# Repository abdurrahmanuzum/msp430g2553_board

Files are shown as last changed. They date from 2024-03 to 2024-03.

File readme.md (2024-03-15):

MSP430G2553 board with CH340 USB-UART bridge for programming.

**This board cannot do proper debugging.**

For programming script, see: https://github.com/gbhug5a/MSP430-BSL/tree/master

Can be run with the command: `<script_path>\BSLDEMO-2.01c.exe -cCOM<port#> -m1 -ijevpr <TI_HEX_filename.txt>`

Or can be embedded into the Code Composer Studio as a post-build step. Change the `<TI_HEX_filename.txt>` to `${BuildArtifactFileBaseName}.txt`. This will make the "Build" button to flash the program after building. (If building actually occurs, remember that the IDE will not build the identical project twice unless forced to. "nothing to build...")

CCS doesn't generate the output file by default, do: Project -> Properties -> Build -> MSP430 HEX Utility -> (1) Tick Enable 'MSP430 Hex Utility' -> Output Format Options -> (2) Select Output format: "TI-TXT hex --ti_txt"

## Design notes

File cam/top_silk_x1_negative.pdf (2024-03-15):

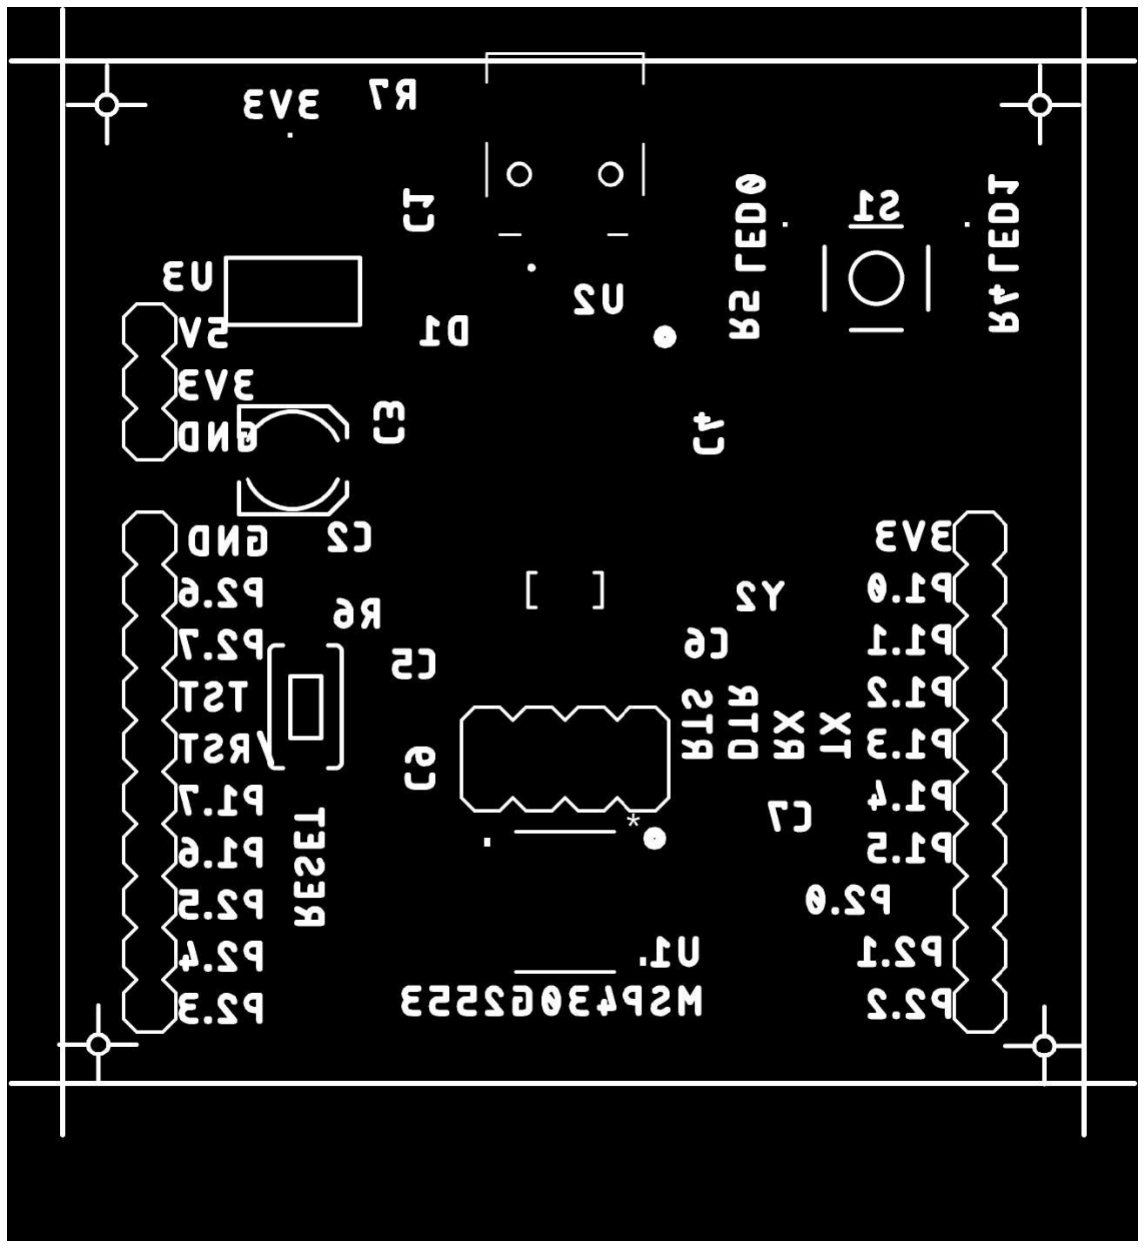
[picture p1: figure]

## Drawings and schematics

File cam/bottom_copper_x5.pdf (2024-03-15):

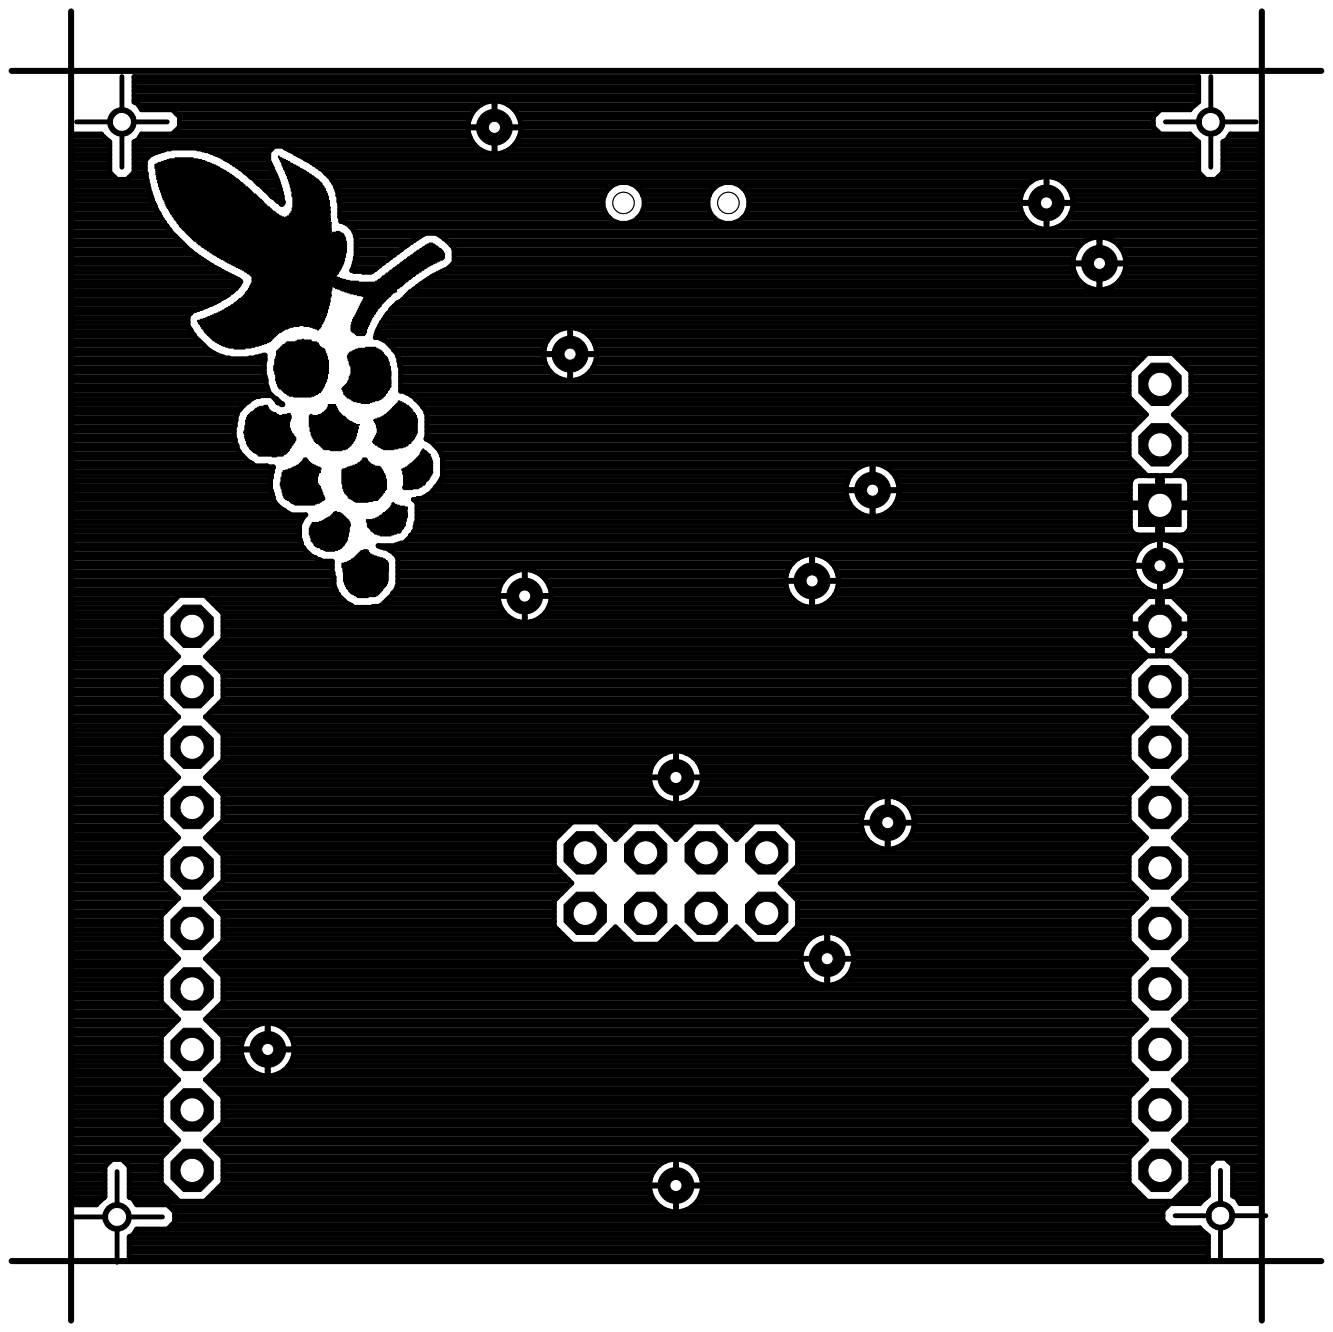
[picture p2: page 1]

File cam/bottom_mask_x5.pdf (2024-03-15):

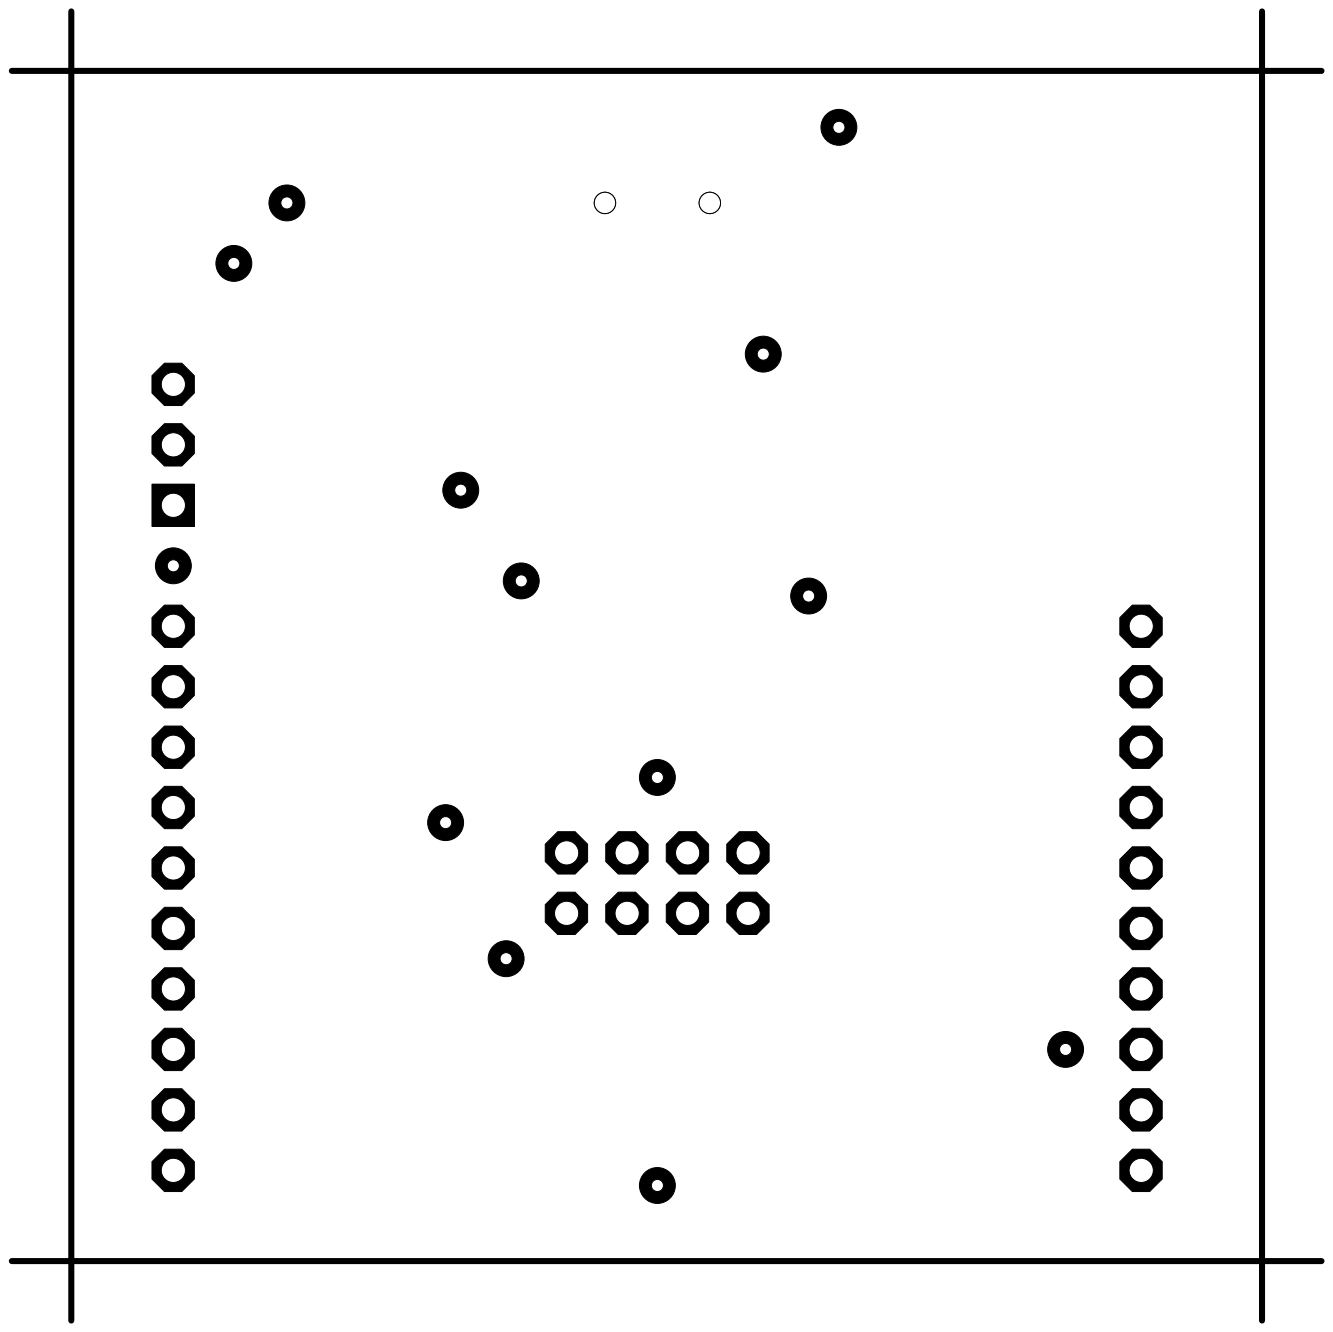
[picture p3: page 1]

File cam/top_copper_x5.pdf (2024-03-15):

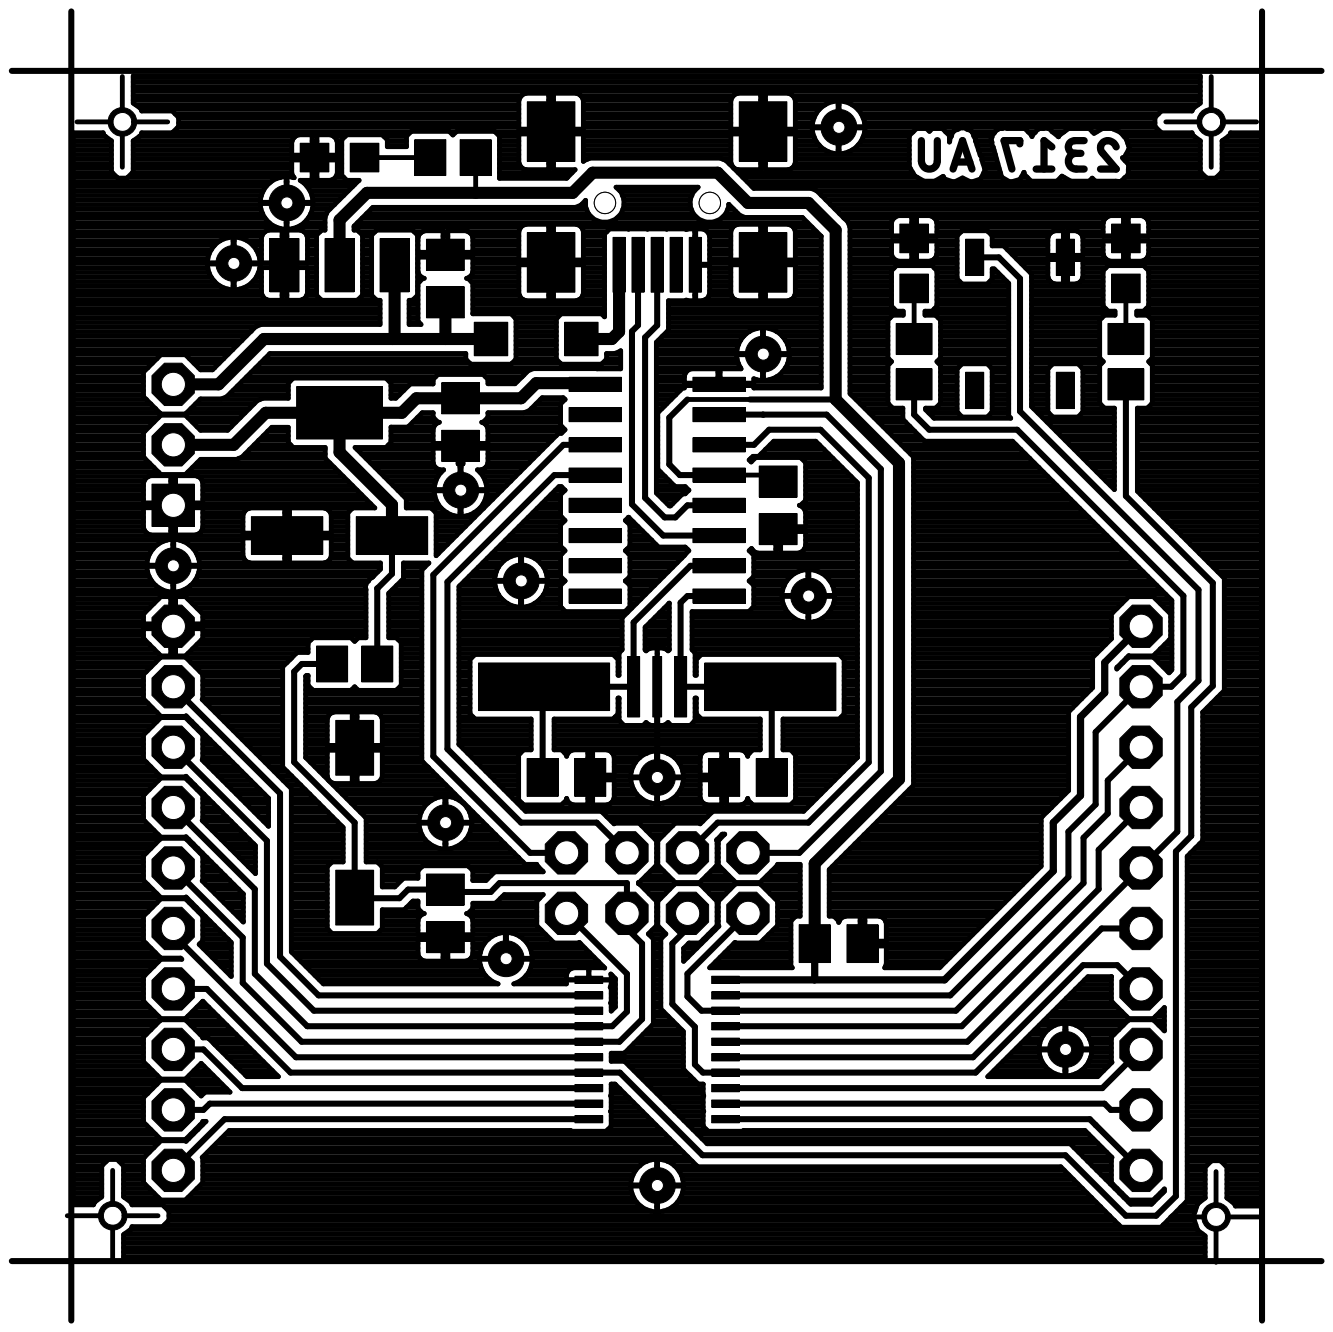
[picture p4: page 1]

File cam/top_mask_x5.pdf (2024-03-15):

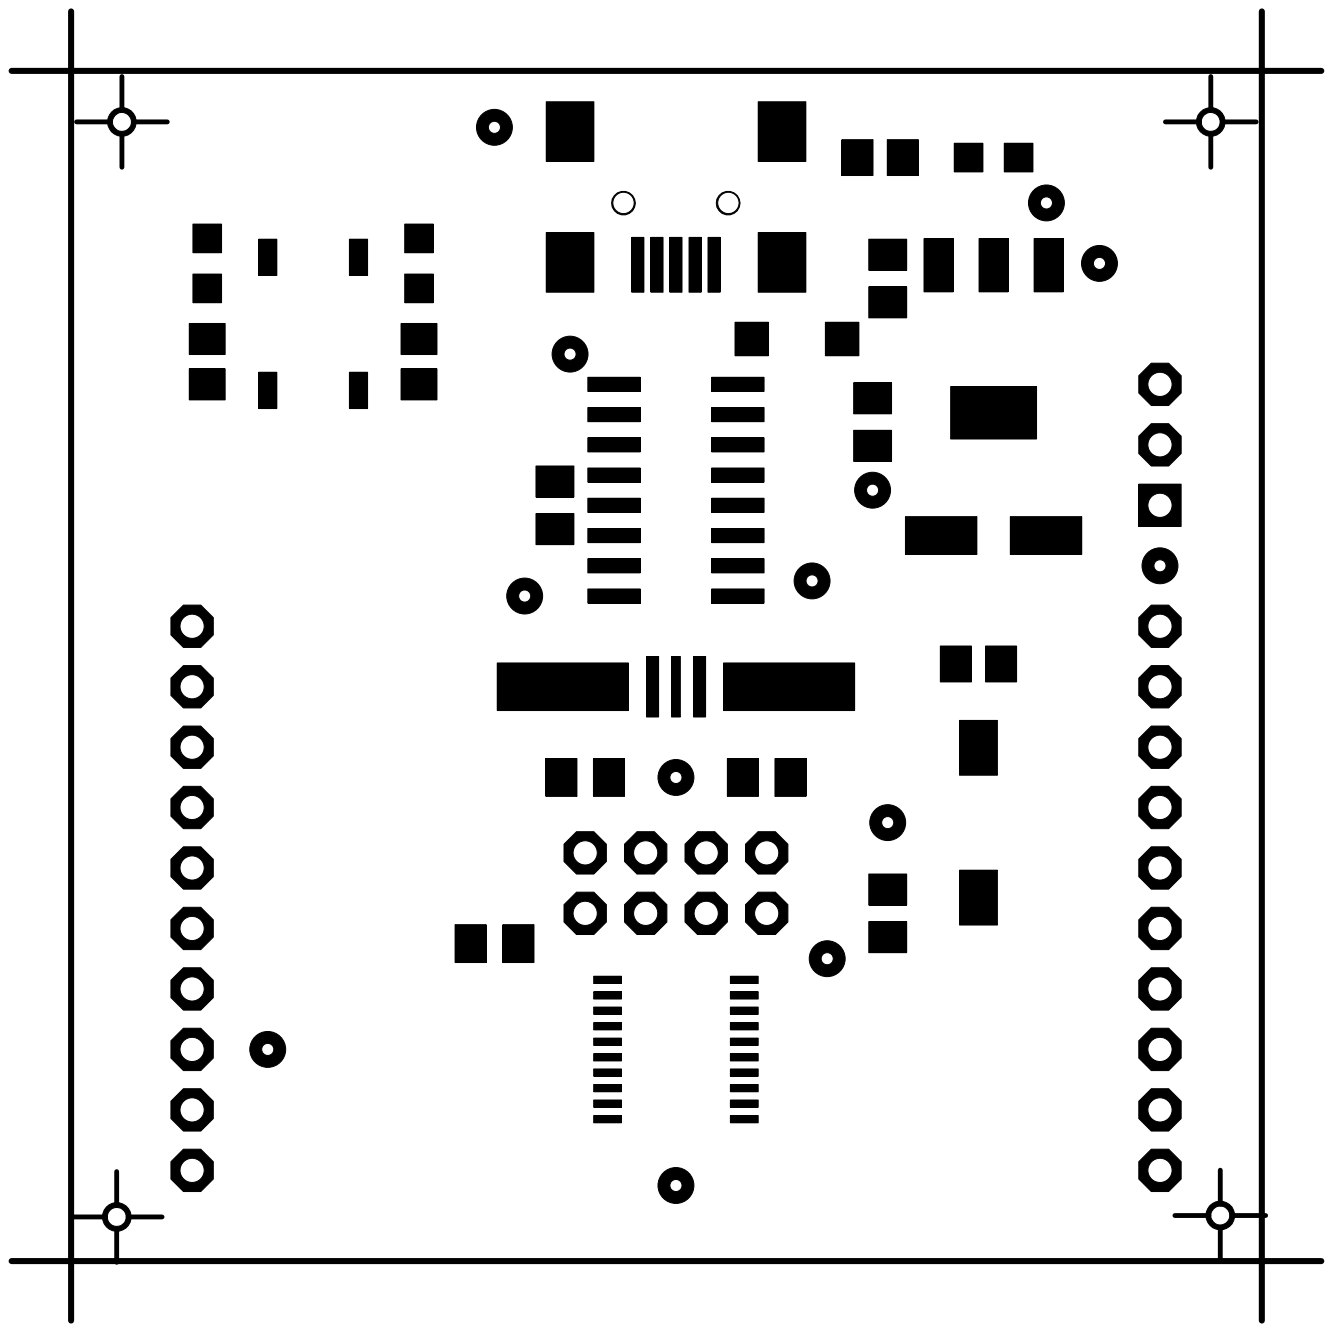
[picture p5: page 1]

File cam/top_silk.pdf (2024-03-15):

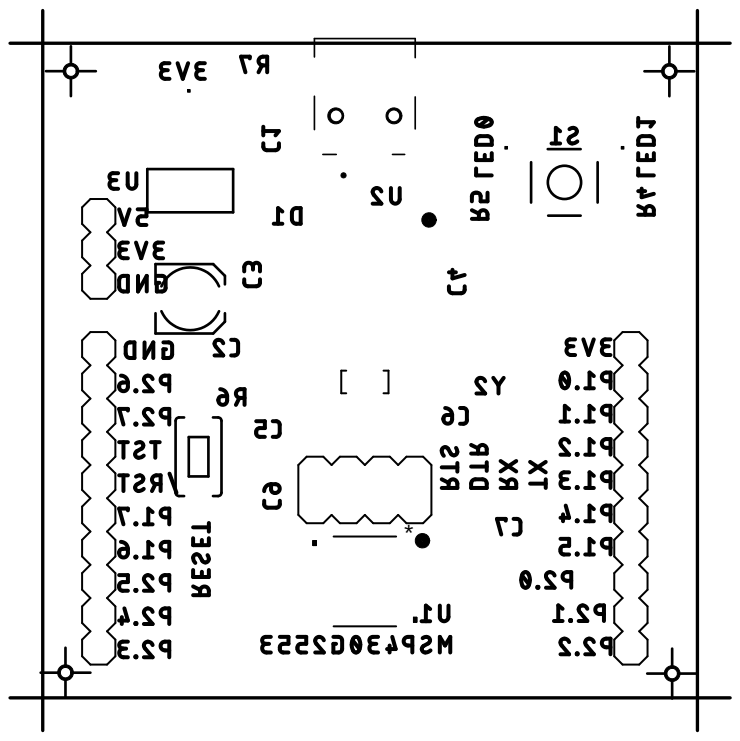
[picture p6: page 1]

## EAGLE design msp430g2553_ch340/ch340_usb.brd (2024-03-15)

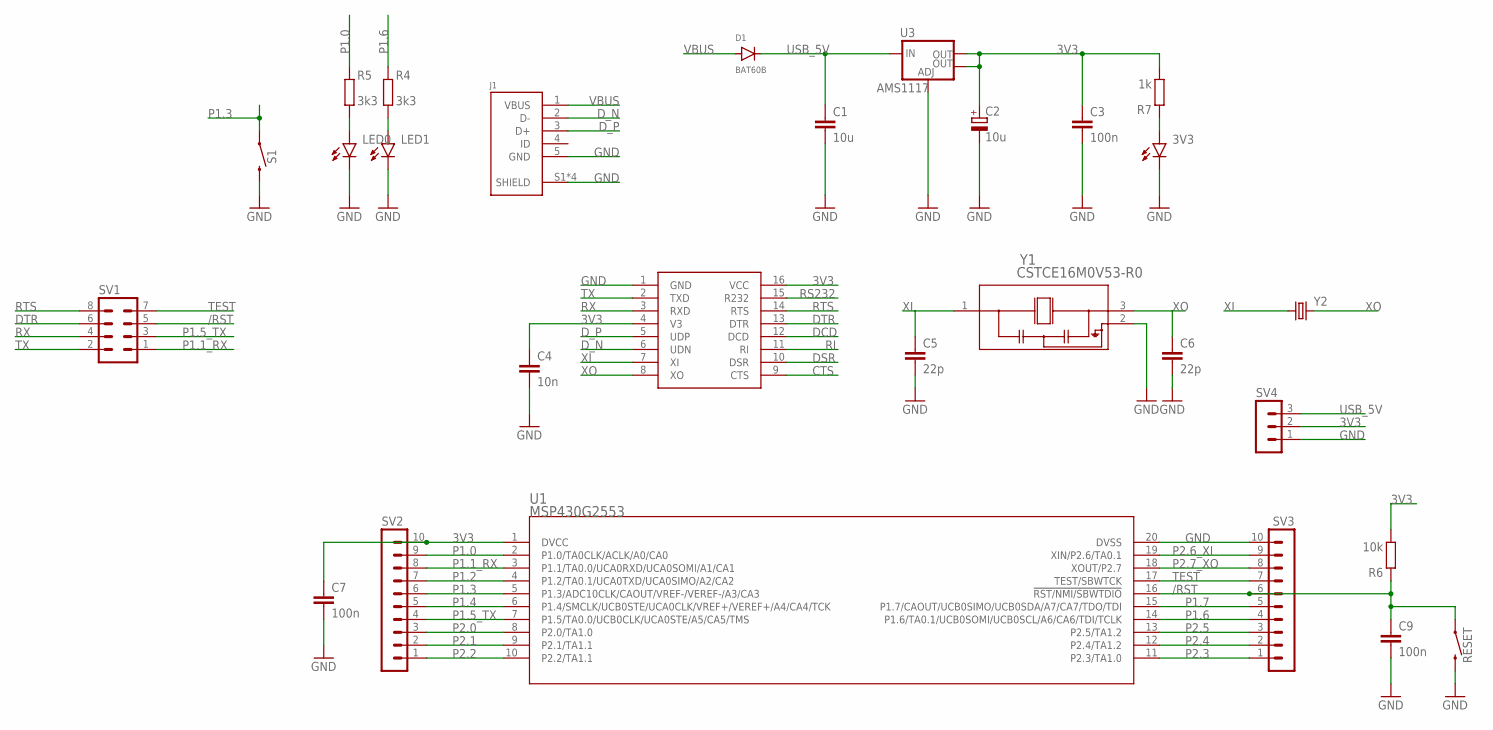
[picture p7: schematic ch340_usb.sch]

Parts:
3V3: PWR; CHIPLED_0805
C1: 10u; C0805K
C2: 10u; 153CLV-0505
C3, C7, C9: 100n; C0805K
C4: 10n; C0805K
C5, C6: 22p; C0805K
D1: BAT60B; SOD123
J1: 1734035-4
LED0, LED1: PWR; CHIPLED_0805
R4, R5: 3k3; R0805
R6: 10k; R0805
R7: 1k; R0805
RESET: MOMENTARY-SWITCH-SPST-SMD-6.0X3.5MM; TACTILE_SWITCH_SMD_6.0X3.5MM
S1: MOMENTARY-SWITCH-SPST-SMD-5.2MM; TACTILE_SWITCH_SMD_5.2MM
SV1: MA04-2
SV2, SV3: MA10-1
SV4: MA03-1
U1: MSP430G2553; PW20-L
U2: CH340GSOIC16N; SOIC16N
U3: AMS1117; SOT223
Y1: CSTCE16M0V53-R0; CSTCE_V_MUR
Y2: CSM-7X-DU

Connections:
3V3: C2.+, C3.1, C4.1, C7.1, R6.1, R7.1, SV2.10, SV4.2, U1.1 (DVCC), U2.4 (V3), U2.16 (VCC), U3.2 (OUT), U3.4 (OUT)
/RST: C9.1, R6.2, RESET.1, SV1.5, SV3.6, U1.16 (!RST/NMI/SBWTDIO)
CTS: U2.9 (CTS)
DCD: U2.12 (DCD)
DSR: U2.10 (DSR)
DTR: SV1.6, U2.13 (DTR)
D_N: J1.2 (D-), U2.6 (UDN)
D_P: J1.3 (D+), U2.5 (UDP)
GND: 3V3.C, C1.2, C2.-, C3.2, C4.2, C5.2, C6.2, C7.2, C9.2, J1.5 (GND), J1.S1 (SHIELD), J1.S2 (SHIELD), J1.S3 (SHIELD), J1.S4 (SHIELD), LED0.C, LED1.C, RESET.2, S1.3 (2), SV3.10, SV4.1, U1.20 (DVSS), U2.1 (GND), U3.1 (ADJ), Y1.2
unnamed: LED1.A, R4.1
unnamed: LED0.A, R5.1
unnamed: 3V3.A, R7.2
P1.0: R5.2, SV2.9, U1.2 (P1.0/TA0CLK/ACLK/A0/CA0)
P1.1_RX: SV1.1, SV2.8, U1.3 (P1.1/TA0.0/UCA0RXD/UCA0SOMI/A1/CA1)
P1.2: SV2.7, U1.4 (P1.2/TA0.1/UCA0TXD/UCA0SIMO/A2/CA2)
P1.3: S1.1, SV2.6, U1.5 (P1.3/ADC10CLK/CAOUT/VREF-/VEREF-/A3/CA3)
P1.4: SV2.5, U1.6 (P1.4/SMCLK/UCB0STE/UCA0CLK/VREF+/VEREF+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)
P1.5_TX: SV1.3, SV2.4, U1.7 (P1.5/TA0.0/UCB0CLK/UCA0STE/A5/CA5/TMS)
P1.6: R4.2, SV3.4, U1.14 (P1.6/TA0.1/UCB0SOMI/UCB0SCL/A6/CA6/TDI/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)
P1.7: SV3.5, U1.15 (P1.7/CAOUT/UCB0SIMO/UCB0SDA/A7/CA7/TDO/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)
P2.0: SV2.3, U1.8 (P2.0/TA1.0)
P2.1: SV2.2, U1.9 (P2.1/TA1.1)
P2.2: SV2.1, U1.10 (P2.2/TA1.1)
P2.3: SV3.1, U1.11 (P2.3/TA1.0)
P2.4: SV3.2, U1.12 (P2.4/TA1.2)
P2.5: SV3.3, U1.13 (P2.5/TA1.2)
P2.6_XI: SV3.9, U1.19 (XIN/P2.6/TA0.1)
P2.7_XO: SV3.8, U1.18 (XOUT/P2.7)
RI: U2.11 (RI)
RS232: U2.15 (R232)
RTS: SV1.8, U2.14 (RTS)
RX: SV1.4, U2.3 (RXD)
TEST: SV1.7, SV3.7, U1.17 (TEST/SBWTCK)
TX: SV1.2, U2.2 (TXD)
USB_5V: C1.1, D1.C, SV4.3, U3.3 (IN)
VBUS: D1.A, J1.1 (VBUS)
XI: C5.1, U2.7 (XI), Y1.1, Y2.1
XO: C6.1, U2.8 (XO), Y1.3, Y2.2

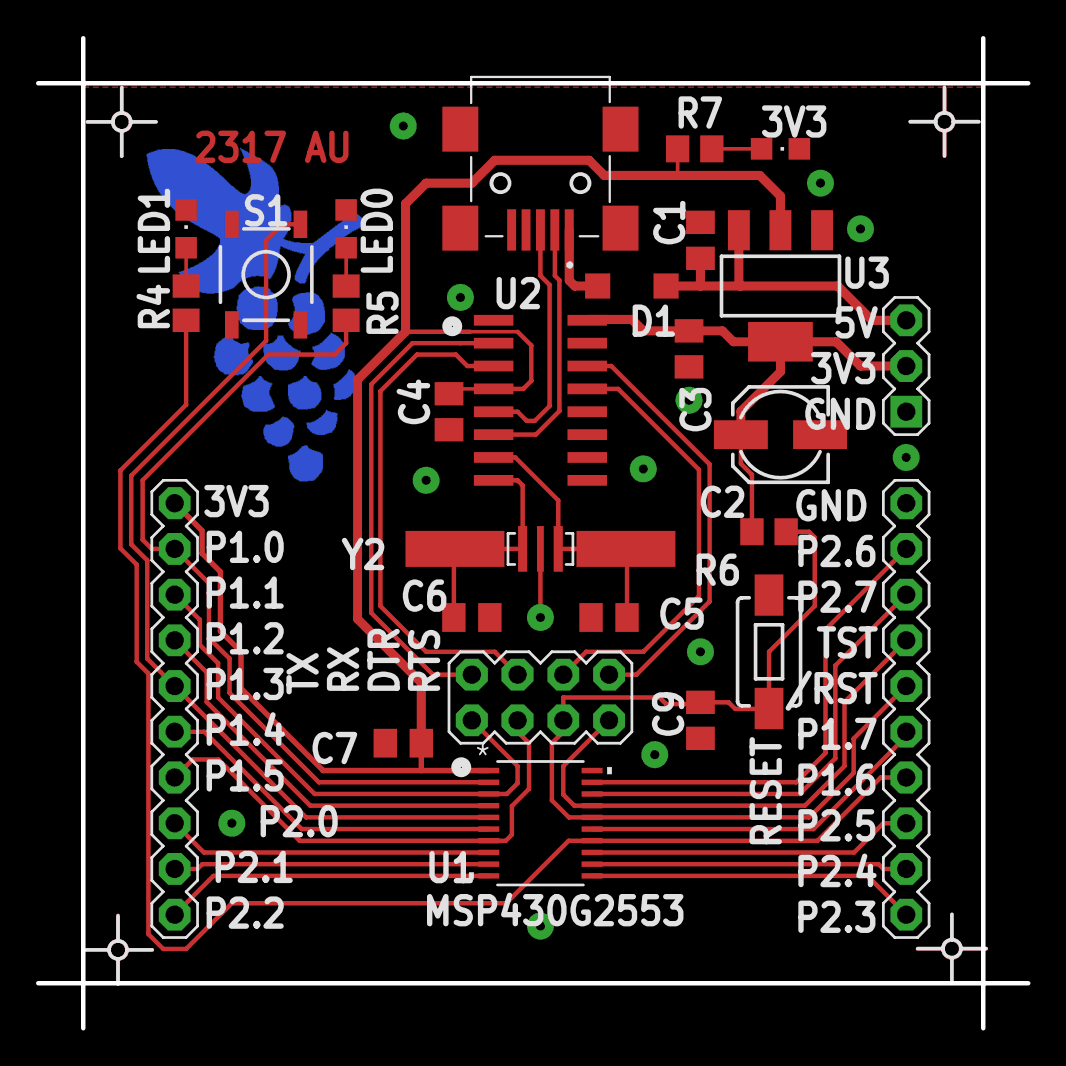
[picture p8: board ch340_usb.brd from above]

Board: 2 copper layers, 55.0 x 55.0 mm, 28 parts (0 on the bottom side), 33 nets.

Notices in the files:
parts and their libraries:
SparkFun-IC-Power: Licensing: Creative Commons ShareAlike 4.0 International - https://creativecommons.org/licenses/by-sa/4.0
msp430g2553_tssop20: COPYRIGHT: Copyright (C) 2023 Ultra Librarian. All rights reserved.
